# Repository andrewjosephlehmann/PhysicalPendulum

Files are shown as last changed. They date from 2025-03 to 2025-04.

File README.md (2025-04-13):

# PhysicalPendulum
My Pendulum apparatus for PHY324's Pendulum Project:





The 3D models were printed at the Center for Entrepreneurship located at the Schwartz Reisman Innovation Campus at the University of Toronto. The 3MF parts were printed with Bambu Labs PLA basic, and the printer was the Bambu Lab X1 Carbon. 

BOM: 

 * Structural
   - 2x 608 Ball Bearings (In our case, we used Bronson Speed Raw Bearings, which are designed to operate without lubricant).
   - 1x 8mm x 100mm Linear Motion Steel Rod
   - 1x 200mm 2020 Aluminum Extrusion
   - 4x 12mm M5 Screws
   - 4x M5 T Slot Nuts
   - 3x 12mm M3 Screws
   - 3x M3 Nuts
   - 1/4x20 - 6 inch in Zinc Plated Threaded Rod
   - 1/4x20 in Nut
   - C Clamp
 * Electronics
   - 1x Raspberry Pi Pico 2 (the original Pico suffices, but the refresh rate is limited).
   - 1x Seeed Studio AS5600 (https://github.com/Seeed-Studio/Seeed_Arduino_AS5600)
   - 1x Female Surface Mount DP9 connector (WARNING: THIS IS NOT WIRED AS A SERIAL PORT)
   - 1x Male DP9 connector
   - 2x 20-pin Header (for Mounting Pico)

Parts: 

   Part (A) : PivotPoint.stl
   Part (B) : Masstorod.stl
   Part (C) : AxleToMagnet.stl
   Part (D) : ThreadToPivot.stl

The project uses Rob Tillaart's AS5600 library, which was modified to work with the Coolterm application. It captures the serial data coming from the pico and allows us to convert it to .csv files for analysis in Python. 

NOTE: Some of the sample data do not include sufficient error bars, as repeated runs are required to quantify the uncertainty of the sample measurements.

The prototype board for the pendulum project:

6F82B84D-5D8C-470F-9DA2-09985D97BB51_1_102_o

32B6ADBF-5FC1-44E5-9E8D-EF83007C5942_1_102_o

The entire apparatus, will provide a better photo once I bring the pendulum back to campus.

427270126-35df8393-7bbd-4267-811a-d3e66f37b43e

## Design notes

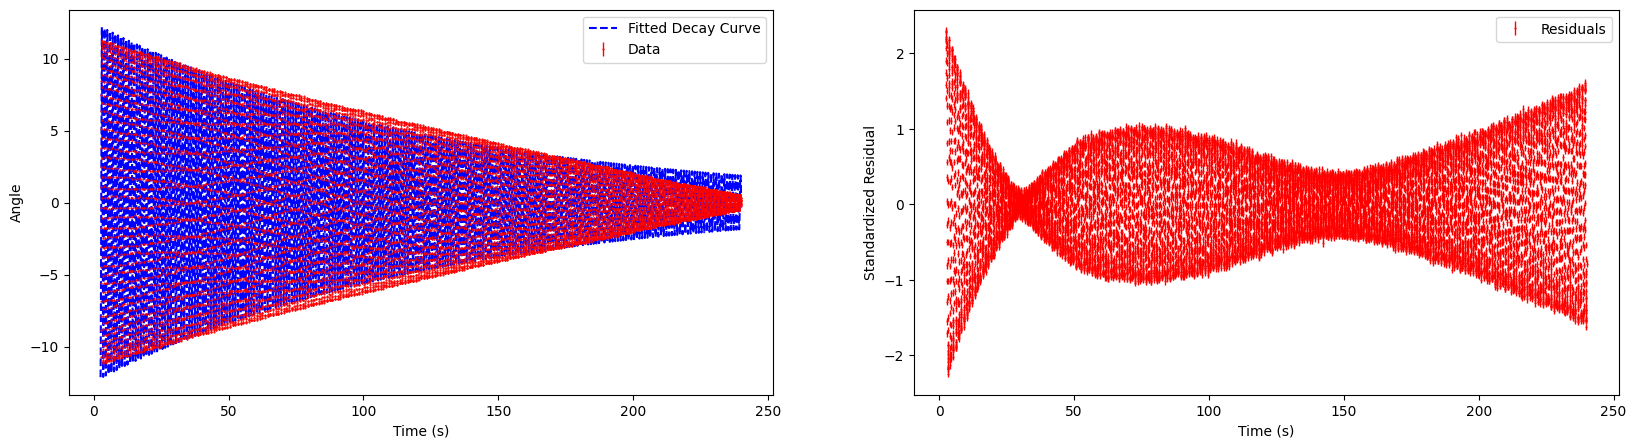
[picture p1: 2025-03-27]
Sample Data/Plot_12Degrees_250g_Mass.png

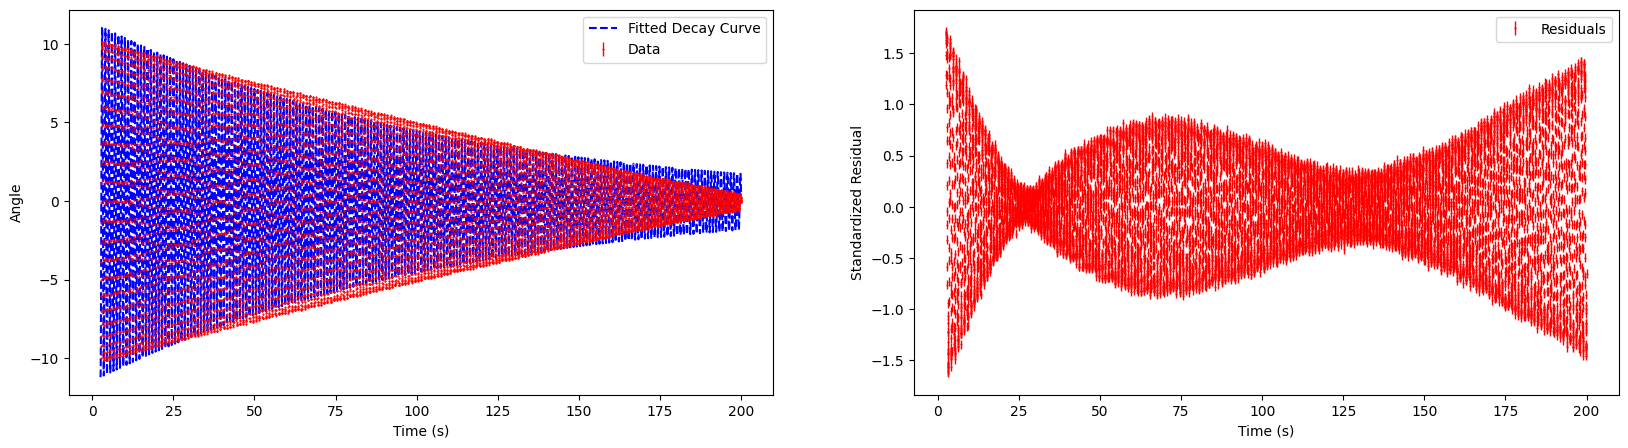
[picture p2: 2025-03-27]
Sample Data/Plot_20Degrees_250g_Mass.png

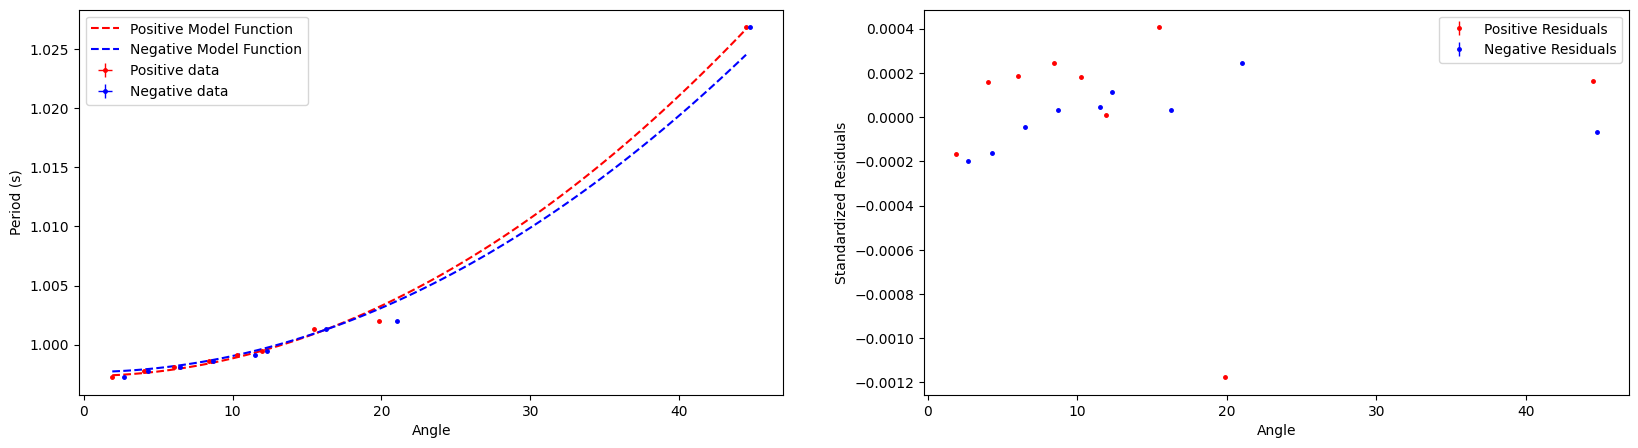
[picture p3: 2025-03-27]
Sample Data/Plot_Symmetry_Verfication_250g_Mass.png

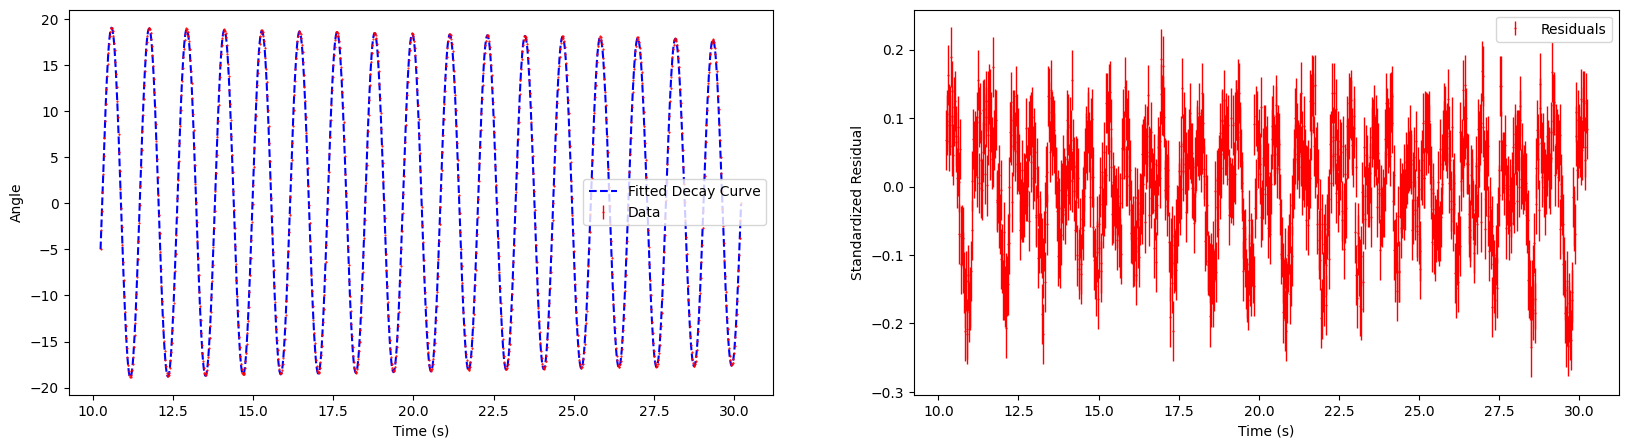
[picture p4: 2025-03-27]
Sample Data/Plot_20Degrees_250g_Mass_Interval.png

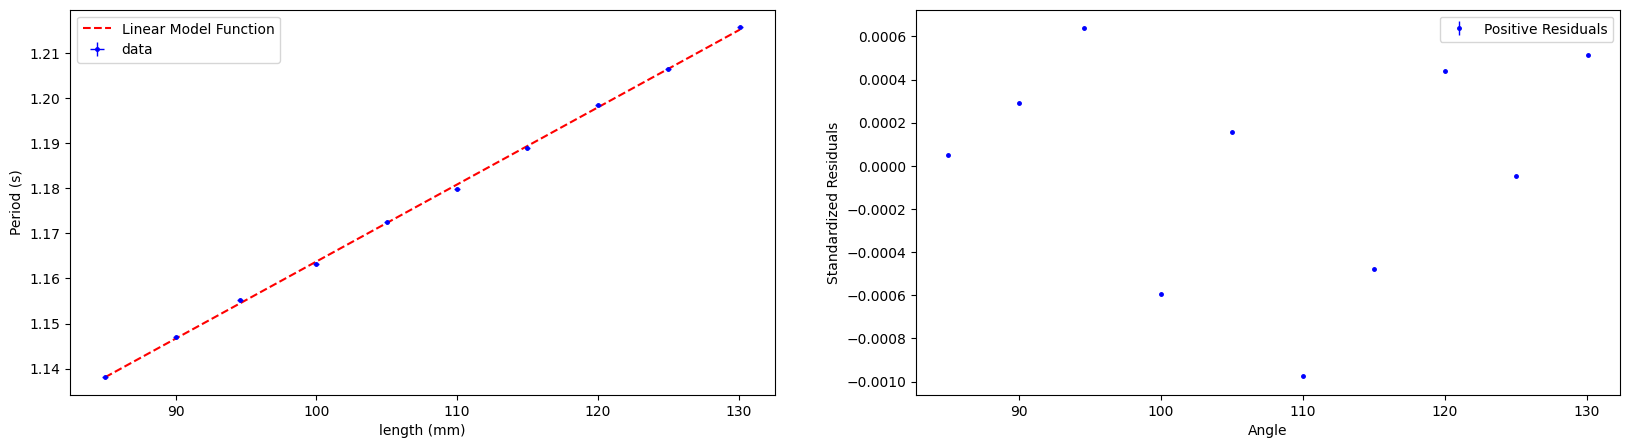
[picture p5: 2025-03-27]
Sample Data/Plot_20Degrees_PeriodvsLength_250g_Mass.png

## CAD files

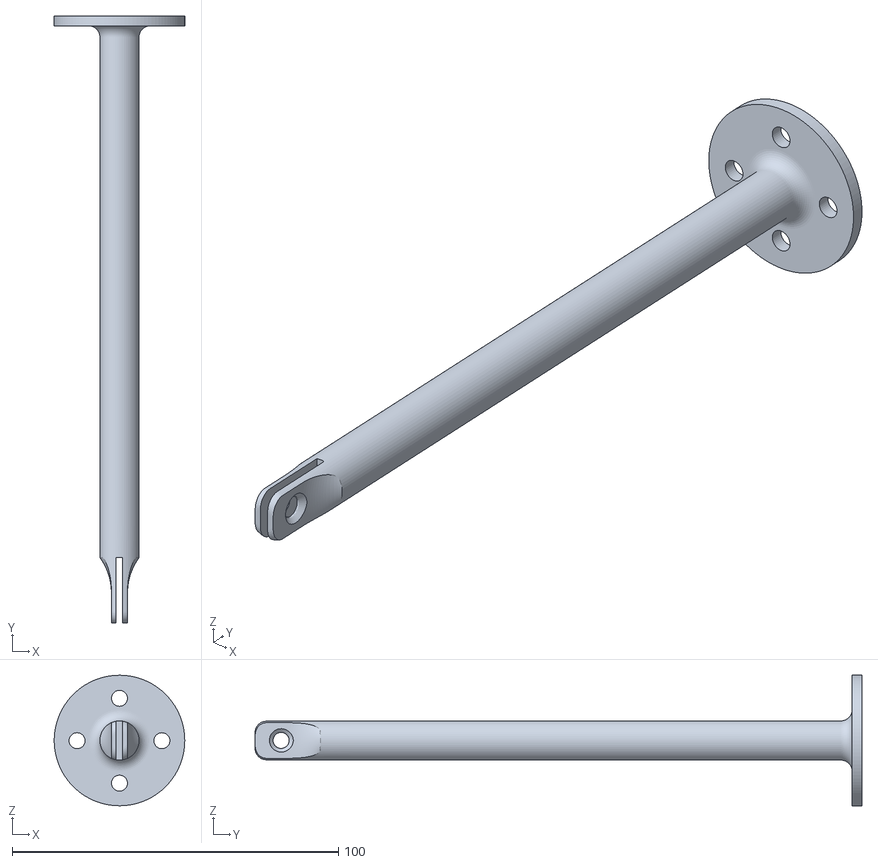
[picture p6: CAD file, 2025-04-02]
3D_files/STL/Masstorod.stl
40.0 x 186.0 x 40.0

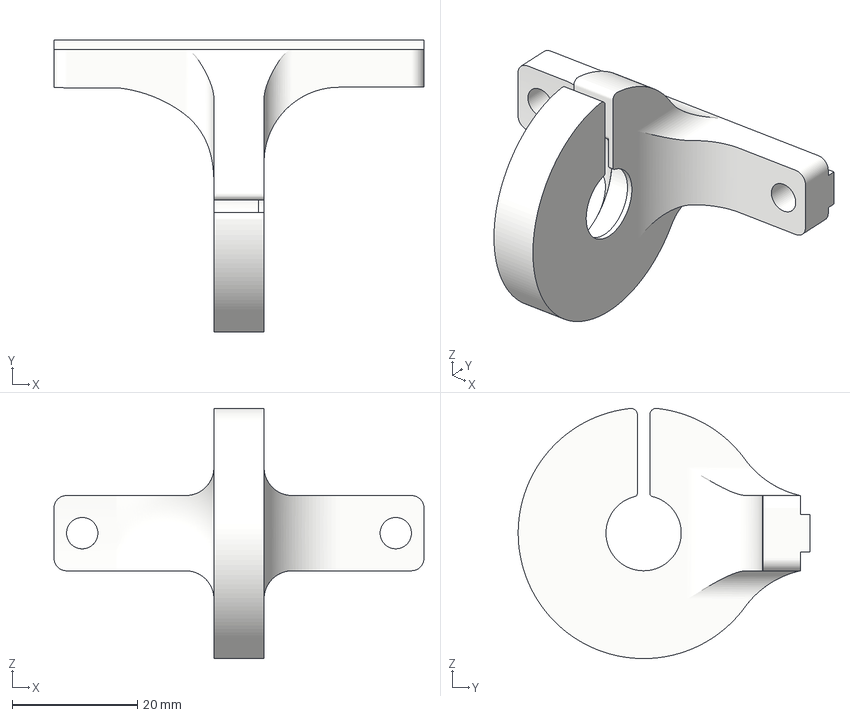
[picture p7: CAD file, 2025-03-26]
3MF_files/PivotPoint.3mf
59.0 x 46.5 x 39.9 mm

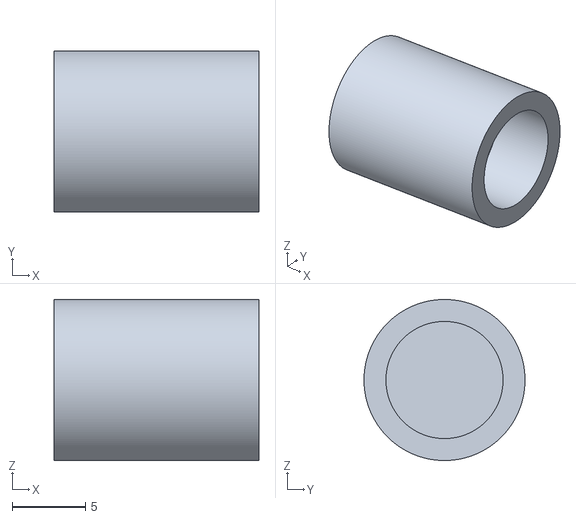
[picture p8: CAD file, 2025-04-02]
3D_files/STL/AxleToMagnet.stl
14.0 x 11.0 x 11.0

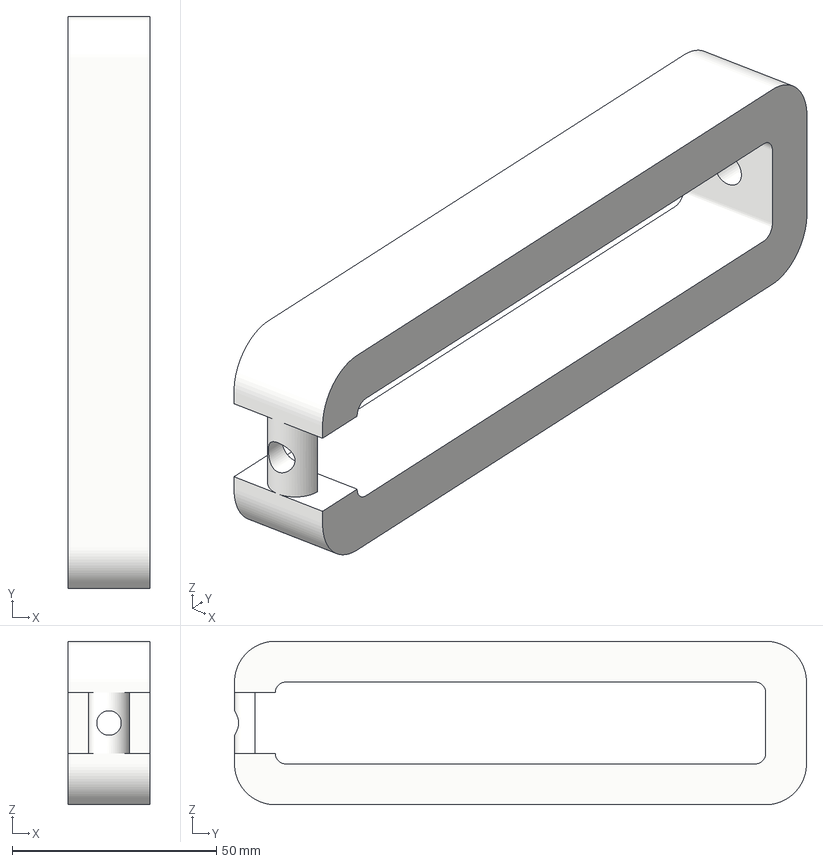
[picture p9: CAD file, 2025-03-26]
3MF_files/Threaded Rod to Mass.3mf
20.0 x 140.0 x 40.0 mm

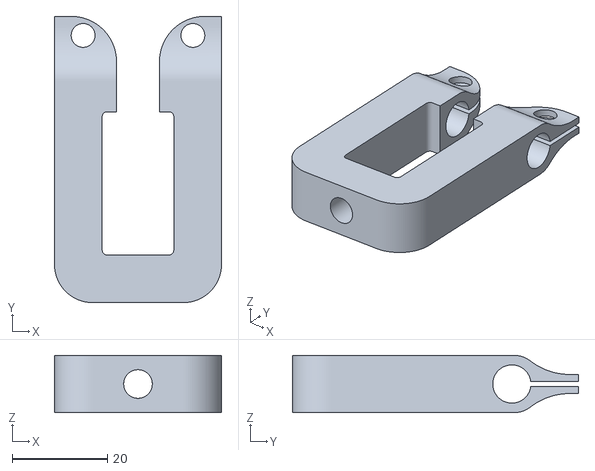
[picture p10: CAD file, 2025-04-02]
3D_files/STL/ThreadToPivot.stl
35.0 x 60.0 x 12.0

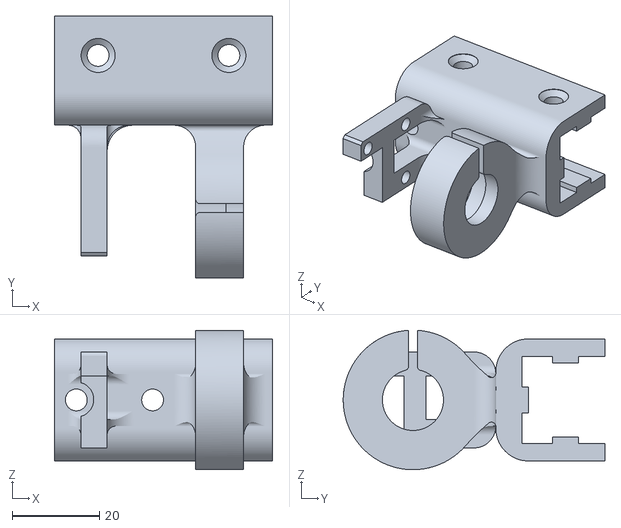
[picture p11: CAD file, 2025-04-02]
3D_files/STL/SensorMount.stl
50.0 x 60.0 x 32.0

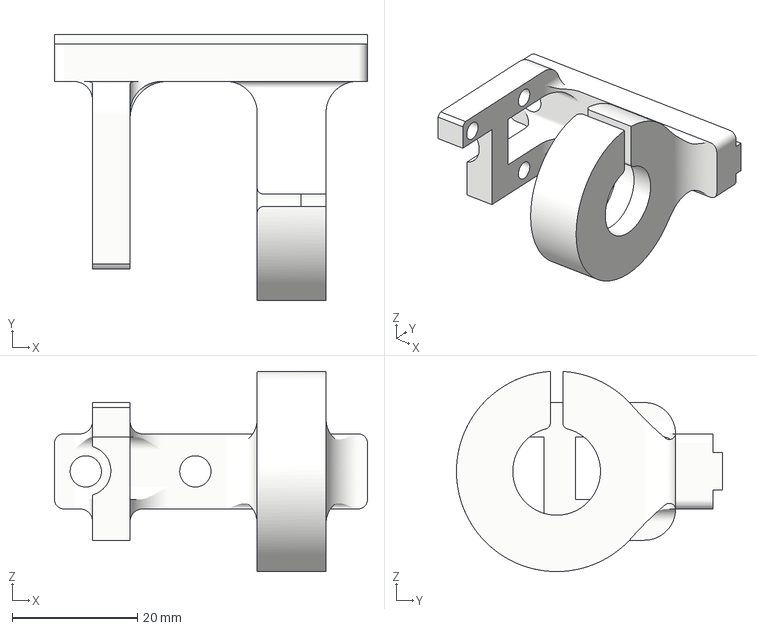
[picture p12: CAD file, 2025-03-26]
3MF_files/AMS5600_Holder.3mf
50.0 x 42.5 x 32.0 mm

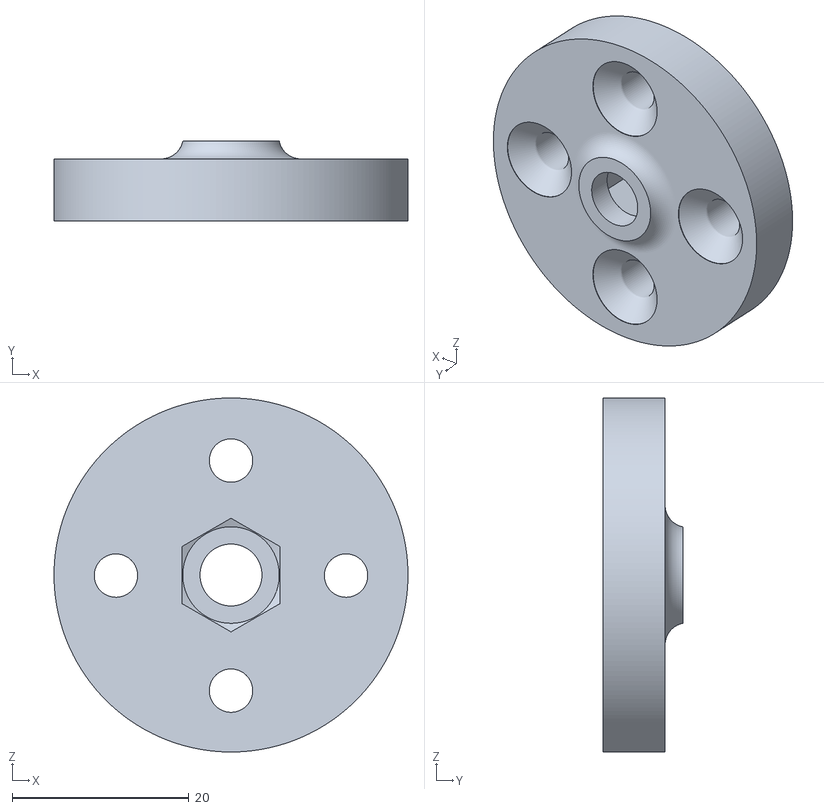
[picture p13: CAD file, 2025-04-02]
3D_files/STL/RodToThread.stl
40.0 x 9.00 x 40.0

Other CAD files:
3MF_files/8mmRod_to_Magnet.3mf
3MF_files/CarbonSteelRod_to_ThreadedRod.3mf
3D_files/Pendulum.f3z
3D_files/STL/PivotPoint.stl

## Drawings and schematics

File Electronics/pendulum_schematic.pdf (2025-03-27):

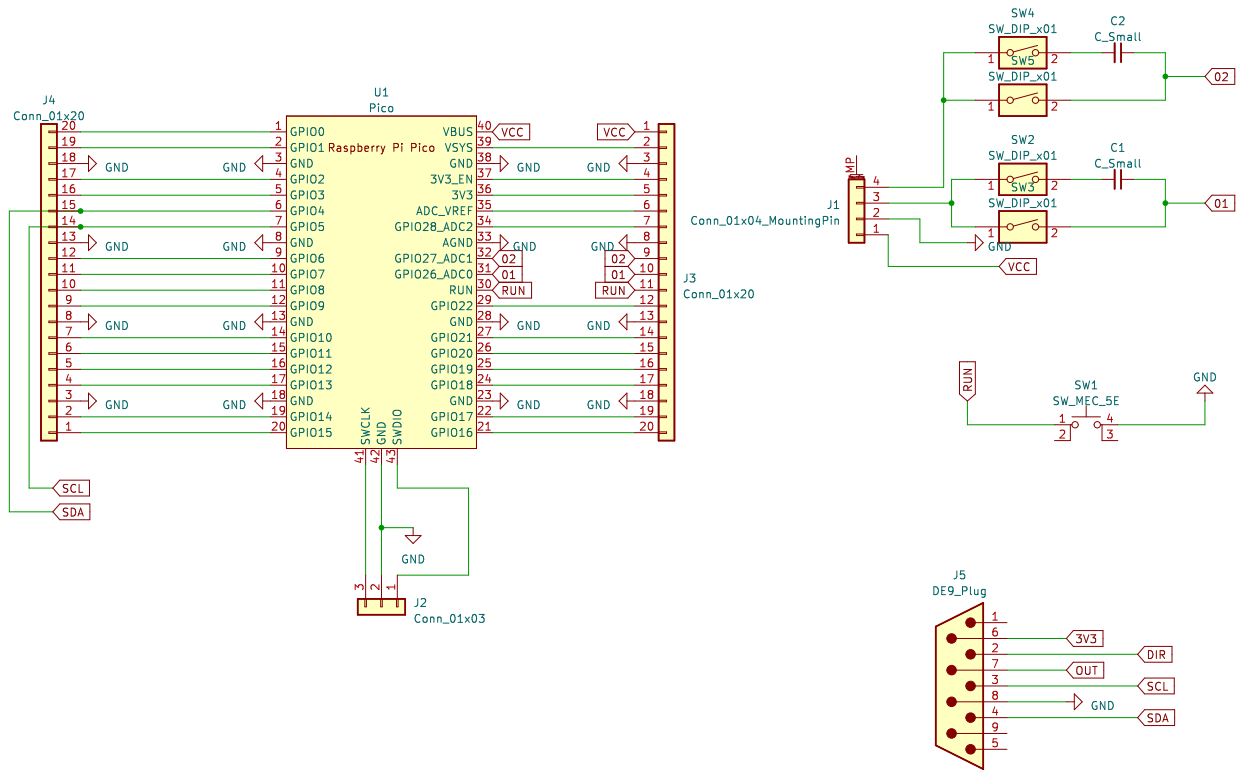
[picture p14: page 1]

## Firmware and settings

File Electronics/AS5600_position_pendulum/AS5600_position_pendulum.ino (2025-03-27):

//
//    FILE: AS5600_position_speed.ino
//  AUTHOR: Rob Tillaart
// PURPOSE: demo compare performance with update flag
//     URL: https://github.com/RobTillaart/AS5600
//
//  Examples may use AS5600 or AS5600L devices.
//  Check if your sensor matches the one used in the example.
//  Optionally adjust the code.



// Modified by Andrew Lehmann For PHY324 Pendulum Project. 



#include "AS5600.h"

//  Uncomment the line according to your sensor type
// AS5600L as5600;   //  use default Wire
AS5600 as5600;   //  use default Wire

float angleOffset = 0.0;
uint32_t startTime = 0;

void setup()
{
  Serial.begin(115200);
  while (!Serial);
  Serial.println(__FILE__);
  Serial.print("AS5600_LIB_VERSION: ");
  Serial.println(AS5600_LIB_VERSION);
  Serial.println();

  Wire.begin();

  as5600.begin();  //  set direction pin.
  as5600.setDirection(AS5600_CLOCK_WISE);  //  default, just be explicit.

  Serial.println(as5600.getAddress());

  int b = as5600.isConnected();
  Serial.print("Connect: ");
  Serial.println(b);

  delay(1000);
  startTime = millis(); // Initialize start time
}

void loop()
{
  static uint32_t lastTime = 0;

  // Check for serial input
  if (Serial.available()) {
    String command = Serial.readStringUntil('\n');
    command.trim();
    if (command.equalsIgnoreCase("reset position")) {
      angleOffset = as5600.getCumulativePosition() / 4096.0 * 360.0;
      Serial.println("Position reset.");
    } else if (command.equalsIgnoreCase("reset time")) {
      startTime = millis();
      Serial.println("Time reset.");
    }
  }

  // Update every 20 ms
  if (millis() - lastTime >= 20)
  {
    lastTime = millis();
    float currentAngle = as5600.getCumulativePosition() / 4096.0 * 360.0;
    uint32_t elapsedTime = (millis() - startTime); 
    Serial.print(currentAngle - angleOffset);
    Serial.print(";");
    Serial.print(as5600.getRevolutions());
    Serial.print(";");
    Serial.println(elapsedTime);
  }
}
